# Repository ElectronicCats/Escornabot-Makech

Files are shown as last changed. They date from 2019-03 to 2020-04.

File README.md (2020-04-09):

<a href="https://electroniccats.com/store/escornabot-makech/">
  
</a>

View this project on [CADLAB.io](https://cadlab.io/project/1721). 

# Escornabot Makech
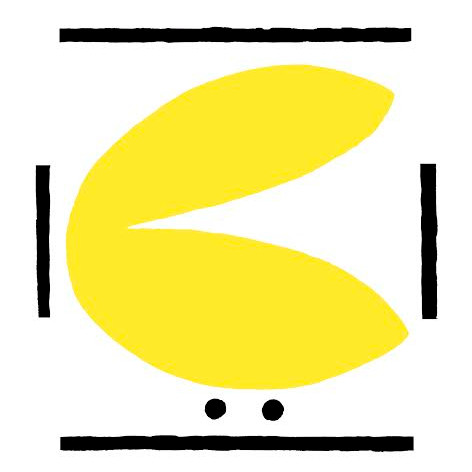
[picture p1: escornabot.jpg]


OSHW

**[OSHW] MX000009 | Certified open source hardware |** [oshwa.org/cert.](https://www.oshwa.org/cert)

Escornabot es un proyecto de código/hardware abierto cuyo objetivo es acercar la robótica y la programación a los niños y niñas.

El Escornabot básico puede programarse con los botones para ejecutar secuencias de movimientos. A partir de aquí, la imaginación es el único límite en las posibilidades.

## Makech
Diseño de robot basado en el Escornabot Ogaki, creado con el microcontrolador SAMD21 Cortex M0 de 32 bits completamente hecho en KiCAD, especialmente creado para enseñar programación con Arduino, MakeCode y CircuitPython.

Al tener todos los circuitos integrados, elimina la necesidad de cablear, minimizando los errores de electrónica, lo que conlleva un incremento en el tiempo dedicado a programación y al conocimiento de nuevos lenguajes de programación.

Con amor para todo el mundo desde Aguascalientes - México.

- Consigue tu kit, visita: [https://electroniccats.com](https://electroniccats.com)

## Ogaki

Diseño de robot basado en el Escornabot, completamente hecho en KiCAD. 

Con amor para todo el mundo desde Malmo - Suecia.

# Créditos

- Escorna CPU 2.20 by [Xdesig](https://github.com/xdesig)

- Los creadores originales de [Escornabot](www.escornabot.com), su comunidad de usuarios y desarrolladores 

# Autor

**Makech - Andrés Sabas and Joe at Electronic Cats**

_Electronic Cats es una empresa de hardware libre hecho en México_

**Ogaki - J. Garcia at abierto.cc**

_Abierto es una inciativa de D. Cuartielles gracias a la generosa aportación de la Fundación PUIG por intermediación de la Fundación Ashoka de cara a contribuir a la creación de material educativo de libre acceso y circulación_

**Escorna CPU 2.20 - XDESIG**

_Nature's walking, Percorrendo a Natureza. Deseñando Electrónica_

# License

Attribution-ShareAlike 4.0 International (CC BY-SA 4.0)
 
Makech - Designed by Electronic Cats.

Hardware released under an CERN Open Hardware Licence v1.2. See the LICENSE_HARDWARE file for more information.

Electronic Cats is a registered trademark, please do not use if you sell these PCBs.

3 Mar 2019

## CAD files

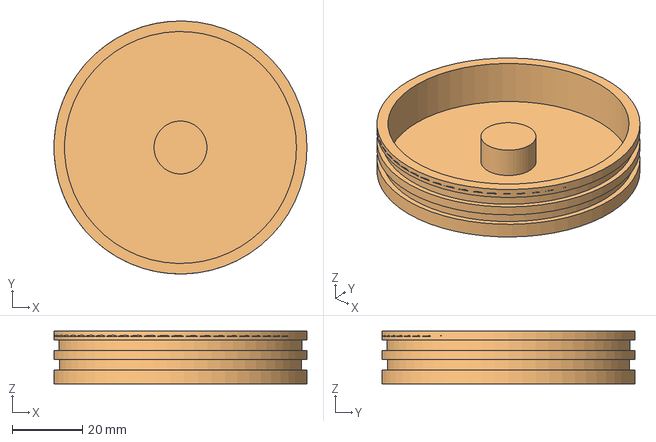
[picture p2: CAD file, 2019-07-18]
Makech/3d/FreeCAD/llantas.FCStd
72.0 x 72.0 x 15.0 mm

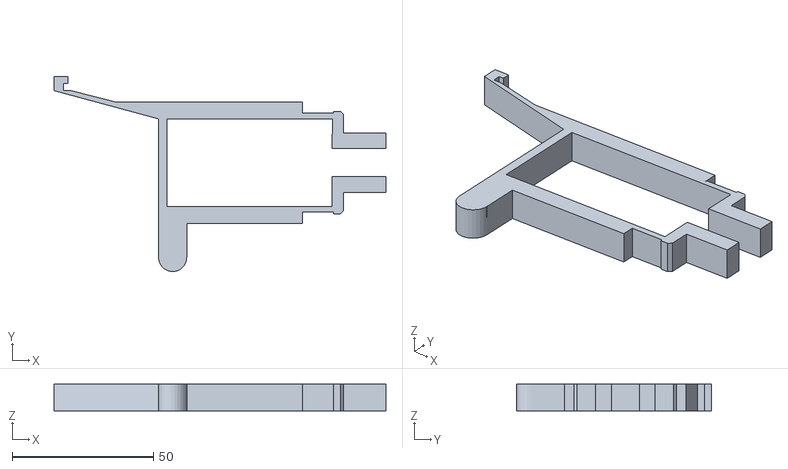
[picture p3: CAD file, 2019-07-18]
Makech/3d/modelado/sop_bat.stl
117.5 x 69.0 x 9.50

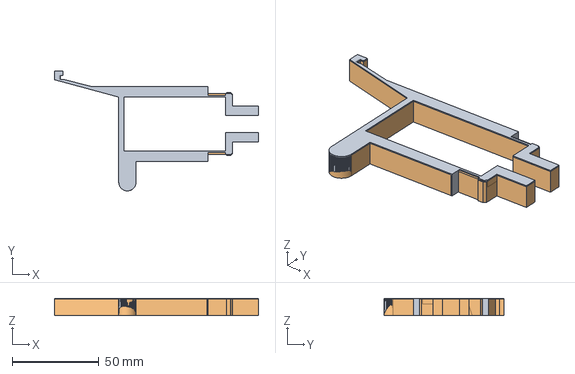
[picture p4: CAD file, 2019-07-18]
Makech/3d/FreeCAD/sop_baterias.FCStd
117.5 x 69.1 x 10.0 mm

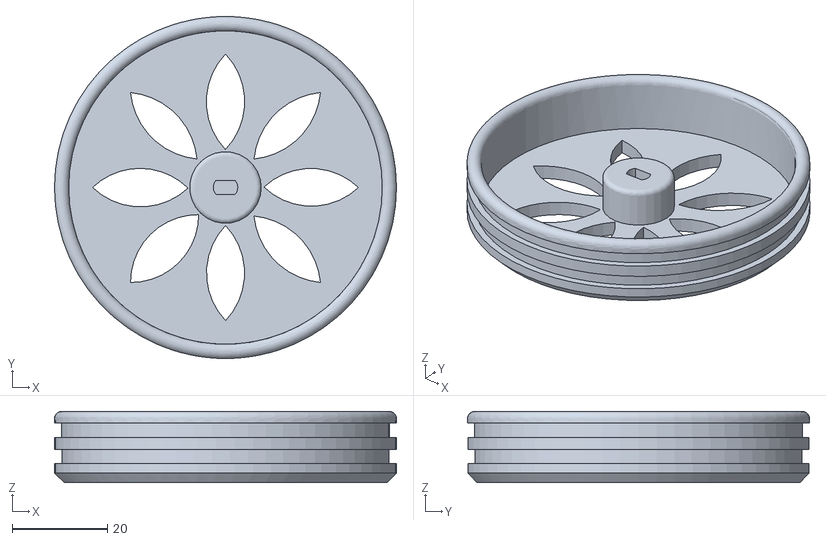
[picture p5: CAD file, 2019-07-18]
Makech/3d/modelado/llanta.stl
72.0 x 72.0 x 15.0

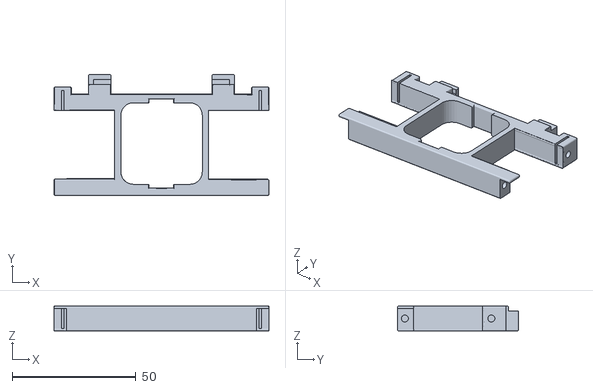
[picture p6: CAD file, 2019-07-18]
Makech/3d/modelado/sop_mot.stl
87.0 x 49.0 x 10.0

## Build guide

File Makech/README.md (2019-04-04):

# Escornabot Makech

Diseño de robot basado en el Escornabot Ogaki, creado con el microcontrolador SAMD21 Cortex M0 de 32 bits completamente hecho en KiCAD, especialmente creado para enseñar programación con Arduino, MakeCode y CircuitPython.

Al tener todos los circuitos integrados, elimina la necesidad de cablear, minimizando los errores de electrónica, lo que conlleva un incremento en el tiempo dedicado a programación y al conocimiento de nuevos lenguajes de programación.
Con amor para todo el mundo desde Aguascalientes - México.

# Consigue tu kit

Si quieres conseguir el kit para montarlo, visita: [https://electroniccats.com](https://electroniccats.com)

# Instrucciones de montaje

Puedes ver las instrucciones de montaje paso a paso en:

# Créditos

Los creadores originales de Escornabot y su comunidad de usuarios y desarrolladores

# Autor

Makech - Andrés Sabas at Electronic Cats

# Electronic Cats

Electronic Cats es una hardware libre hecho en México

Makech - Designed by Electronic Cats.

Hardware released under an CERN Open Hardware Licence v1.2. See the LICENSE_HARDWARE file for more information.

Electronic Cats is a registered trademark, please do not use if you sell these PCBs.

3 Mar 2019

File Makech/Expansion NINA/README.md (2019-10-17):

# Upgrade All-in-One ESP32 Firmware

## Uploading Serial Passthrough Code

Lo primero que se debe realizar es instalar la biblioteca "WiFiNINA" en el arduino library manager y cargar al Escornabot el ejemplo **"Serial Passthrough"**, una vez terminada la carga del firmware continue en el siguiente paso

## Subiendo nina-fw con esptool

¡Esta sección asume que usted sabe cómo usar 'esptool' para cargar firmware a su ESP! Si no está seguro, consulte https://github.com/espressif/esptool y busque tutoriales.
Haga clic en el siguiente enlace para descargar el último archivo .bin de nina-fw. Descomprimir que y guardar el archivo .bin a su escritorio .

Si está utilizando macOS o Linux , ejecute el siguiente comando, reemplazándolo /dev/ttys6con el puerto serie de su placa y  NINA_W102-1.3.0con el archivo binario que está actualizando al ESP32.

esptool.py --port /dev/ttyS6 --before no_reset --baud 115200 write_flash 0 NINA_W102-1.3.0.bin

Si está utilizando Windows , ejecute el siguiente comando, reemplazándolo COM7con el puerto serie de su placa y  NINA_W102-1.3.0con el archivo binario que está actualizando al ESP32

esptool.py --port COM7 --before no_reset --baud 115200 write_flash 0 NINA_W102-1.3.0.bin

El comando debería detectar el ESP32 y tardará uno o dos minutos en cargar el firmware. El NeoPixel en su placa parpadeará y parpadeará a medida que se carga el firmware. 

Si ESPTool no detecta el ESP32 , asegúrese de haber subido el archivo .UF2 correcto al gestor de arranque.



Una vez que el firmware está completamente cargado, el ESP32 se reiniciará y el NeoPixel se iluminará en azul. 

## Verificación de la versión de firmware actualizada

Para verificar que todo funcione correctamente, cargaremos un boceto Arduino o un código CircuitPython. 

Si anteriormente estaba usando su ESP32 con Arduino, debe cargar un boceto de Arduino para verificar que todo funcione correctamente y que la versión del nina-fw se correlaciona con la versión que lee el boceto.

Abra Archivo-> Ejemplos-> WiFiNINA-> ScanNetworks y cargue el boceto. Luego, abra el Monitor de serie. Debería ver la versión del firmware impresa en el monitor serie.



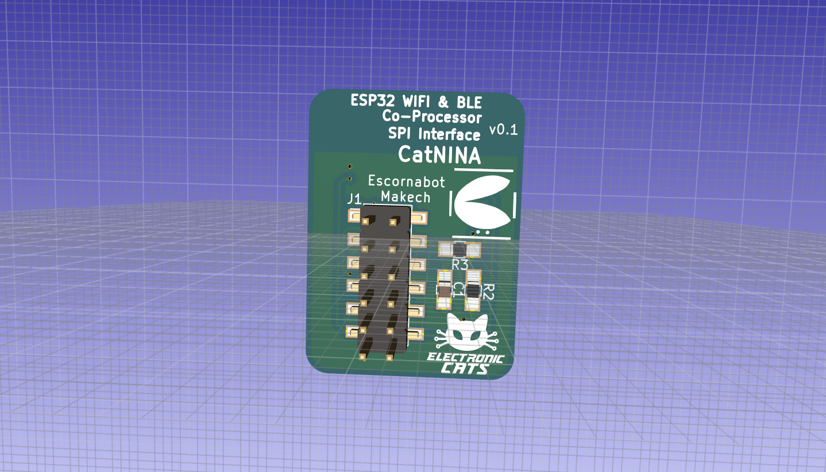
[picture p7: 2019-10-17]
Makech/Expansion NINA/CatNINA_back.png

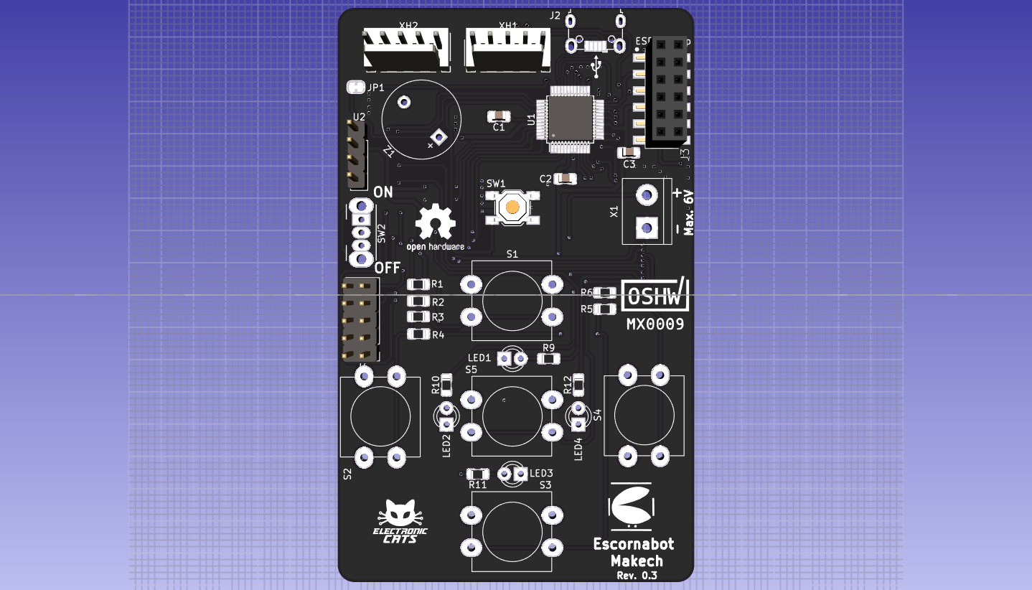
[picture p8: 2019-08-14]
Makech/hardware/KiCad files/Makech_front.png

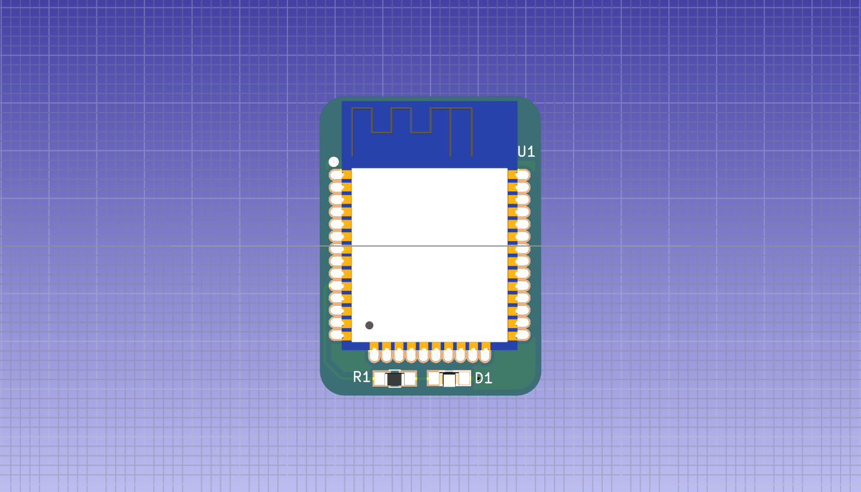
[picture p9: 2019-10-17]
Makech/Expansion NINA/CatNINA.png

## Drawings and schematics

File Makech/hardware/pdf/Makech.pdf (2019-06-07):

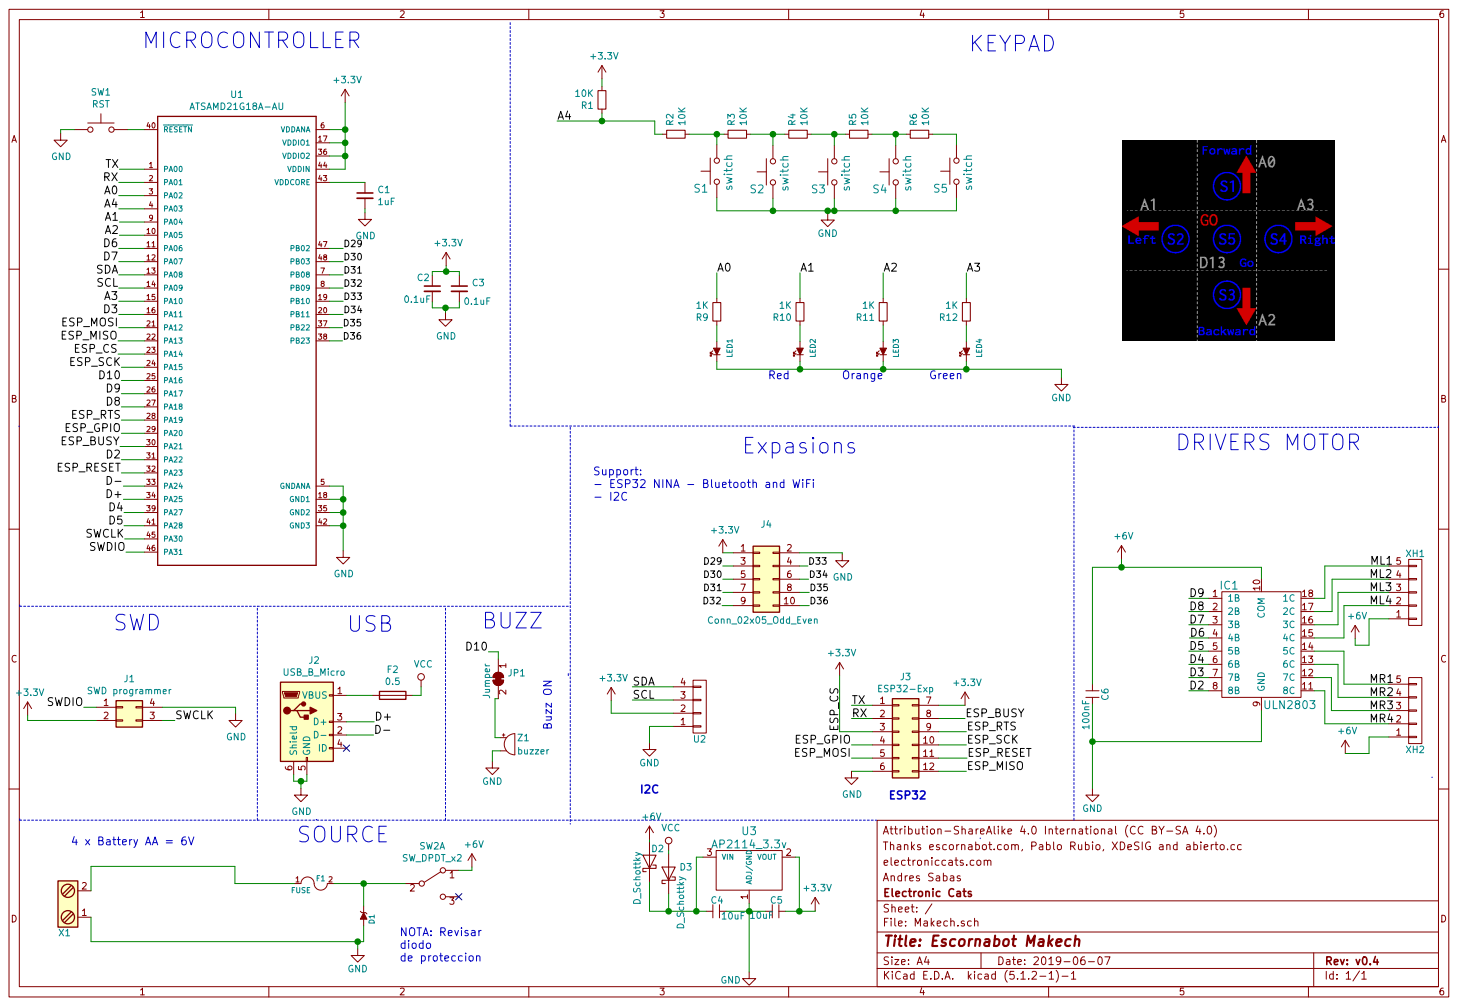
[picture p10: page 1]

- ESP32 NINA - Bluetooth and WiFi

4 | 10
5 | 11

Attribution-ShareAlike 4.0 International (CC BY-SA 4.0)
Thanks escornabot.com, Pablo Rubio, XDeSIG and abierto.cc
File: Makech.sch Sheet: / Electronic Cats Andres Sabas electroniccats.com

Id: 1/1 Title: Escornabot Makech

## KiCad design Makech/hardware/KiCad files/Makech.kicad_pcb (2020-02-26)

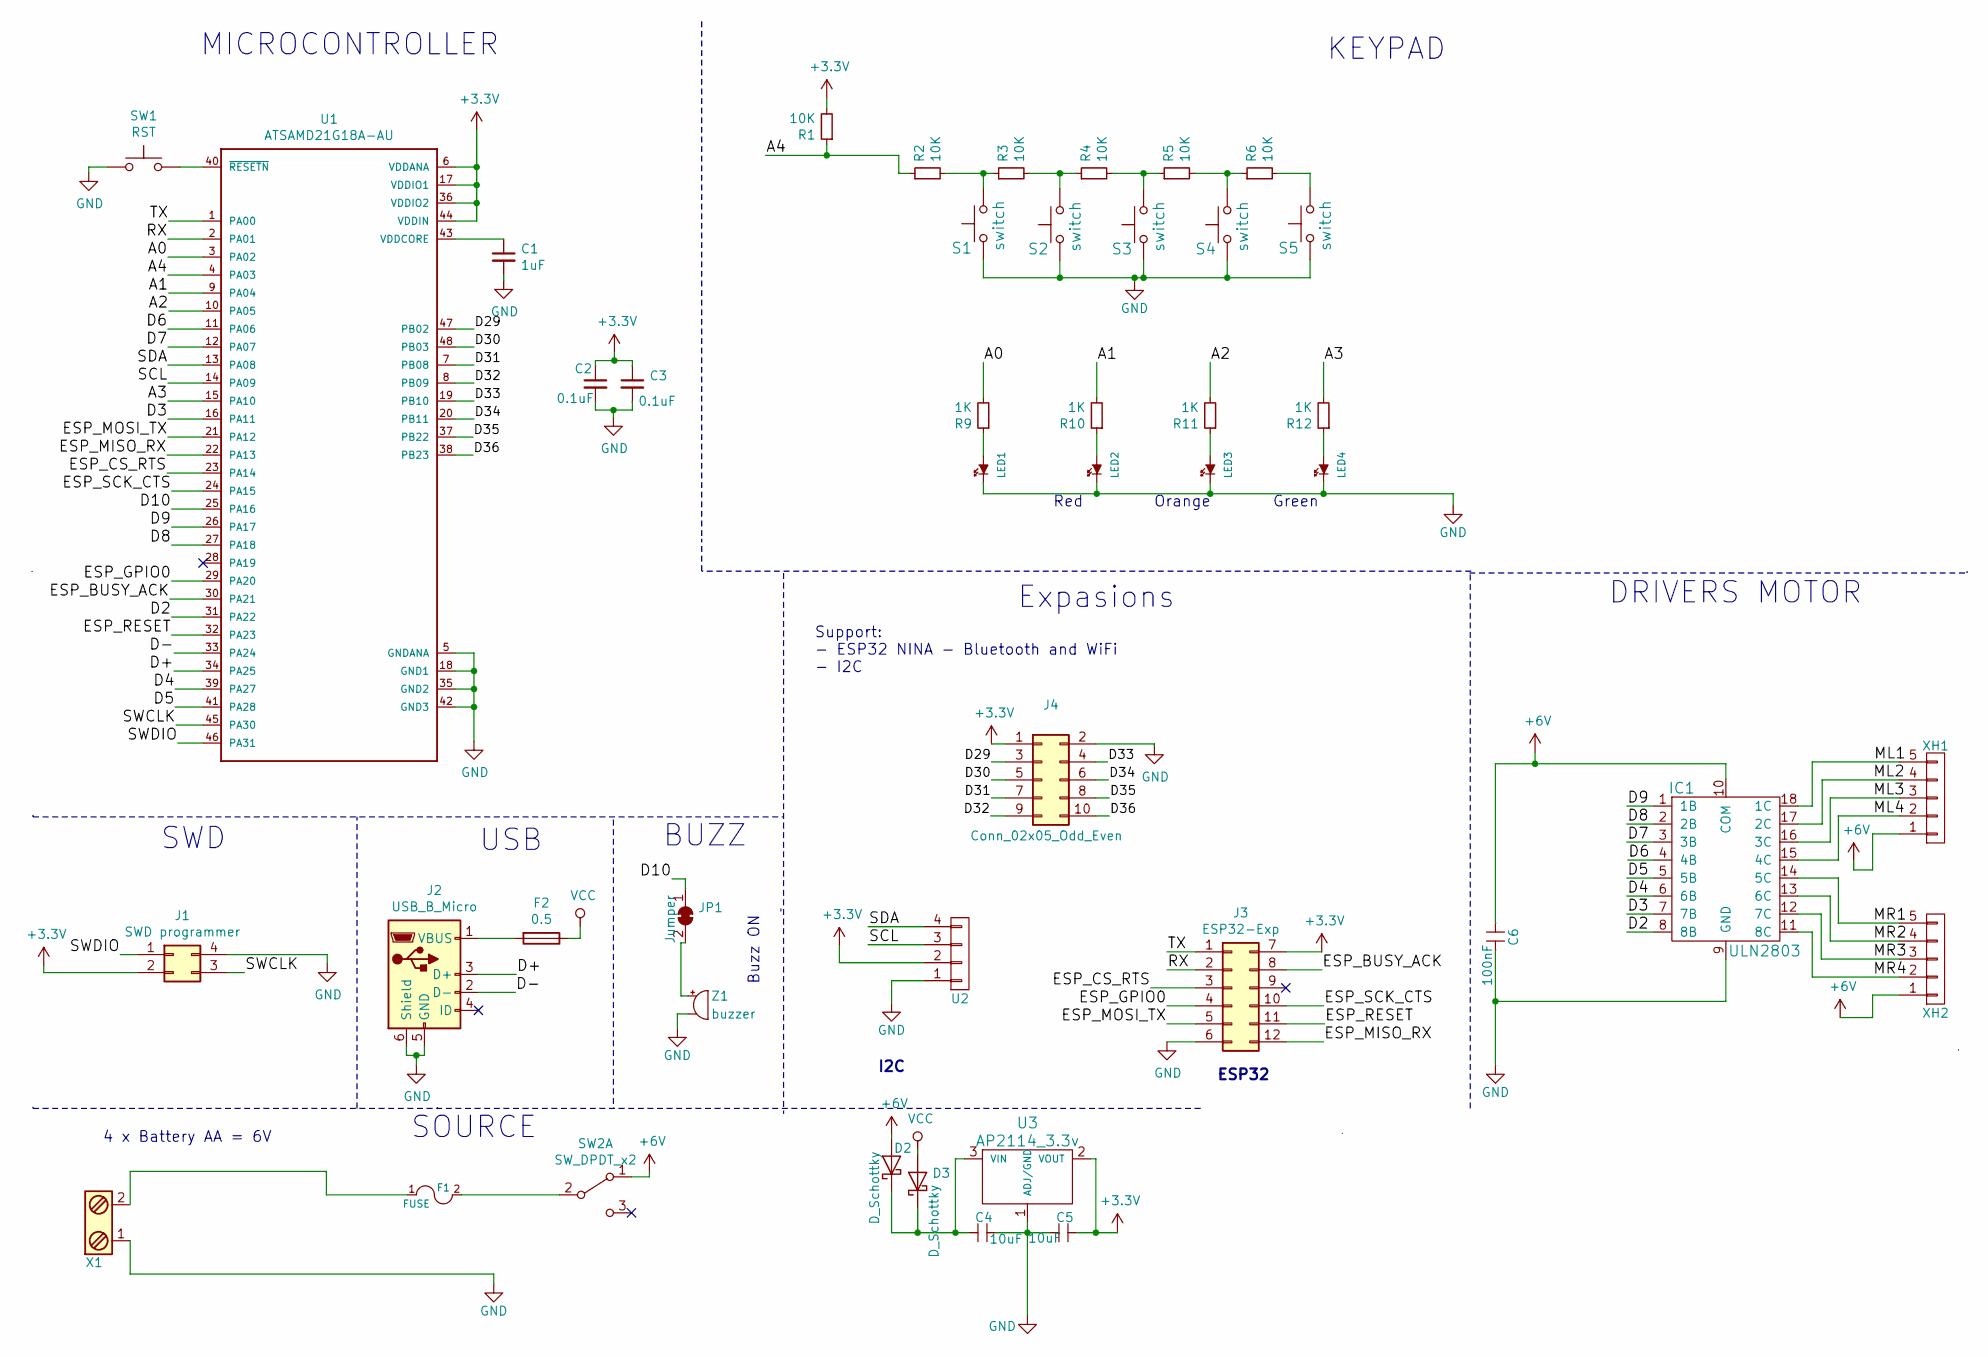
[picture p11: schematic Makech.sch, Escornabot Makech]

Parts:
C1: 1uF; C_0805_2012Metric_Pad1.15x1.40mm_HandSolder
C2, C3: 0.1uF; C_0805_2012Metric_Pad1.15x1.40mm_HandSolder
C4: 10uF; C_0805_2012Metric_Pad1.15x1.40mm_HandSolder
C5: 10uF; C_0805_2012Metric
C6: 100nF; C_0805_2012Metric_Pad1.15x1.40mm_HandSolder
D2, D3: D_Schottky; D_SOD-123
F1: FUSE; R_1812_HandSoldering
F2: 0.5; R_1812_HandSoldering
IC1: ULN2803; SOIC-18W_7.5x11.6mm_P1.27mm
J1: SWD programmer; 621X04245821
J2: USB_B_Micro; U254051N4BH806
J3: ESP32-Exp; 610X1221121
J4: Conn_02x05_Odd_Even; PinHeader_2x05_P2.54mm_Vertical
JP1: Jumper; SolderJumper-2_P1.3mm_Bridged_RoundedPad1.0x1.5mm
LED1, LED2, LED3, LED4: L; LED_D3.0mm
R1, R2, R3, R4, R5, R6: 10K; R_0805_2012Metric_Pad1.15x1.40mm_HandSolder
R9, R10, R11, R12: 1K; R_0805_2012Metric_Pad1.15x1.40mm_HandSolder
S1, S2, S3, S4, S5: switch; SW_PUSH-12mm_Wuerth-430476085716
SW1: RST; SW_SPST_TL3342
SW2: SW_DPDT_x2; SW_CuK_OS102011MA1QN1_SPDT_Angled
U1: ATSAMD21G18A-AU; TQFP-48_7x7mm_P0.5mm
U2: CONN_01X04; PinHeader_1x04_P2.54mm_Vertical
U3: AP2114_3.3v; SOT-223
X1: Screw_Terminal_1x02; TerminalBlock_bornier-2_P5.08mm
XH1, XH2: CONN_01X05; Molex_KK-254_AE-6410-05A_1x05_P2.54mm_Vertical
Z1: buzzer; MagneticBuzzer_ProSignal_ABI-009-RC

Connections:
+3V3: C2.1, C3.1, C5.1, J1.2, J3.7, J4.1, R1.2, U1.6 (VDDANA), U1.17 (VDDIO1), U1.36 (VDDIO2), U1.44 (VDDIN), U2.2, U3.2 (VOUT)
+6V: C6.2, D2.2 (A), IC1.10 (COM), SW2.1 (A), XH1.1, XH2.1
/A0: R9.2, U1.3 (PA02)
/A1: R10.2, U1.9 (PA04)
/A2: R11.2, U1.10 (PA05)
/A3: R12.2, U1.15 (PA10)
/A4: R1.1, R2.1, U1.4 (PA03)
/D2: IC1.8 (8B), U1.31 (PA22)
/D3: IC1.7 (7B), U1.16 (PA11)
/D4: IC1.6 (6B), U1.39 (PA27)
/D5: IC1.5 (5B), U1.41 (PA28)
/D6: IC1.4 (4B), U1.11 (PA06)
/D7: IC1.3 (3B), U1.12 (PA07)
/D8: IC1.2 (2B), U1.27 (PA18)
/D9: IC1.1 (1B), U1.26 (PA17)
/D10: JP1.1 (A), U1.25 (PA16)
/D29: J4.3, U1.47 (PB02)
/D30: J4.5, U1.48 (PB03)
/D31: J4.7, U1.7 (PB08)
/D32: J4.9, U1.8 (PB09)
/D33: J4.4, U1.19 (PB10)
/D34: J4.6, U1.20 (PB11)
/D35: J4.8, U1.37 (PB22)
/D36: J4.10, U1.38 (PB23)
/D+: J2.3 (D+), U1.34 (PA25)
/D-: J2.2 (D-), U1.33 (PA24)
/ESP_BUSY_ACK: J3.8, U1.30 (PA21)
/ESP_CS_RTS: J3.3, U1.23 (PA14)
/ESP_GPIO0: J3.4, U1.29 (PA20)
/ESP_MISO_RX: J3.12, U1.22 (PA13)
/ESP_MOSI_TX: J3.5, U1.21 (PA12)
/ESP_RESET: J3.11, U1.32 (PA23)
/ESP_SCK_CTS: J3.10, U1.24 (PA15)
/ML1: IC1.18 (1C), XH1.5
/ML2: IC1.17 (2C), XH1.4
/ML3: IC1.16 (3C), XH1.3
/ML4: IC1.15 (4C), XH1.2
/MR1: IC1.14 (5C), XH2.5
/MR2: IC1.13 (6C), XH2.4
/MR3: IC1.12 (7C), XH2.3
/MR4: IC1.11 (8C), XH2.2
/RX: J3.2, U1.2 (PA01)
/SCL: U1.14 (PA09), U2.3
/SDA: U1.13 (PA08), U2.4
/SWCLK: J1.3, U1.45 (PA30)
/SWDIO: J1.1, U1.46 (PA31)
/TX: J3.1, U1.1 (PA00)
GND: C1.2, C2.2, C3.2, C4.1, C5.2, C6.1, IC1.9 (GND), J1.4, J2.5 (GND), J2.6 (Shield), J3.6, J4.2, LED1.1 (K), LED2.1 (K), LED3.1 (K), LED4.1 (K), S1.1, S2.1, S3.1, S4.1, S5.1, SW1.1, U1.5 (GNDANA), U1.18 (GND1), U1.35 (GND2), U1.42 (GND3), U2.1, U3.1 (ADJ/GND), X1.1, Z1.2
unnamed: C1.1, U1.43 (VDDCORE)
unnamed: C4.2, D2.1 (K), D3.1 (K), U3.3 (VIN)
unnamed: F1.2, SW2.2 (B)
unnamed: F1.1, X1.2
unnamed: F2.2, J2.1 (VBUS)
unnamed: JP1.2 (B), Z1.1
unnamed: LED1.2 (A), R9.1
unnamed: LED2.2 (A), R10.1
unnamed: LED3.2 (A), R11.1
unnamed: LED4.2 (A), R12.1
unnamed: R2.2, R3.1, S1.2
unnamed: R3.2, R4.1, S2.2
unnamed: R4.2, R5.1, S3.2
unnamed: R5.2, R6.1, S4.2
unnamed: R6.2, S5.2
unnamed: SW1.2, U1.40 (~RESETN~)
VCC: D3.2 (A), F2.1

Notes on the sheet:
KEYPAD
BUZZ
Buzz ON
I2C
Expasions
Red
Orange
Green
4 x Battery AA = 6V
MICROCONTROLLER
Support: - ESP32 NINA - Bluetooth and WiFi - I2C
DRIVERS MOTOR
USB
SWD
ESP32
SOURCE

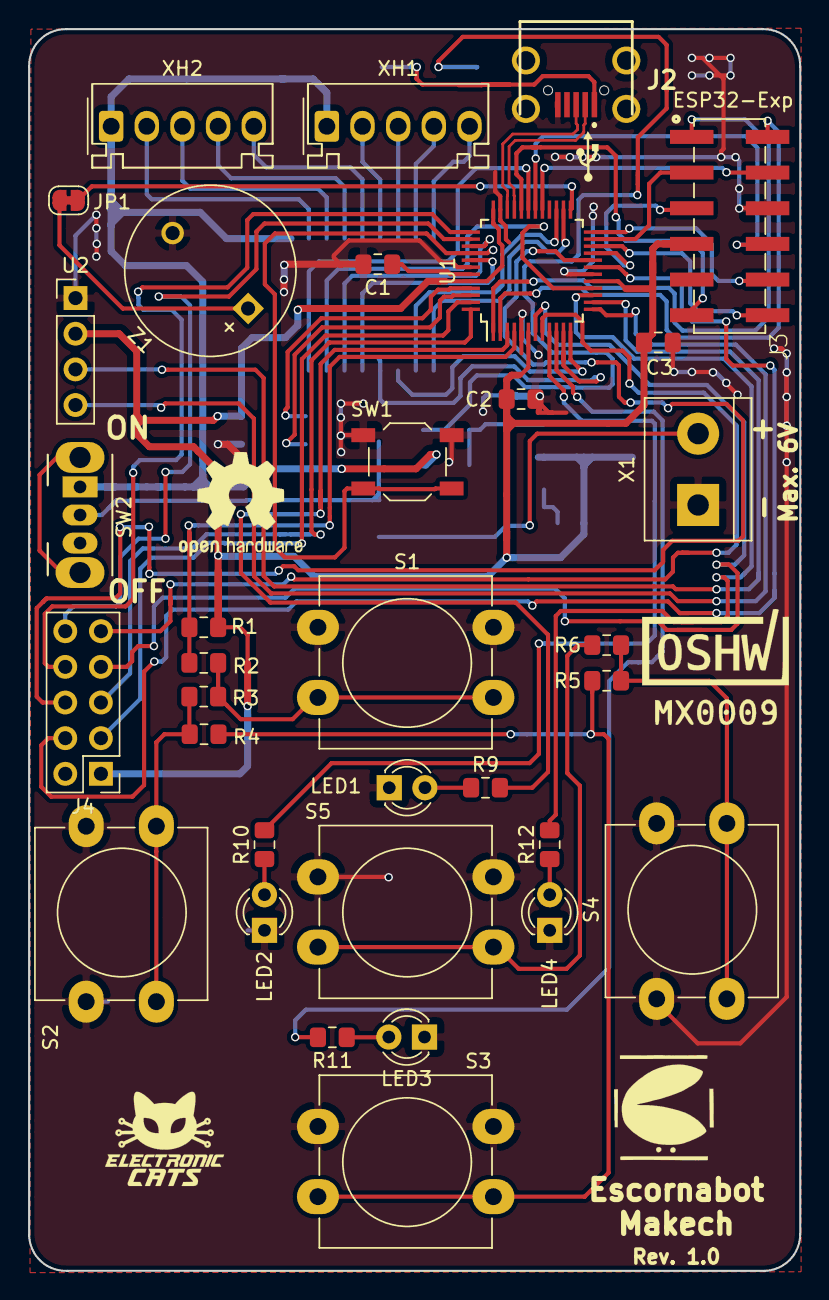
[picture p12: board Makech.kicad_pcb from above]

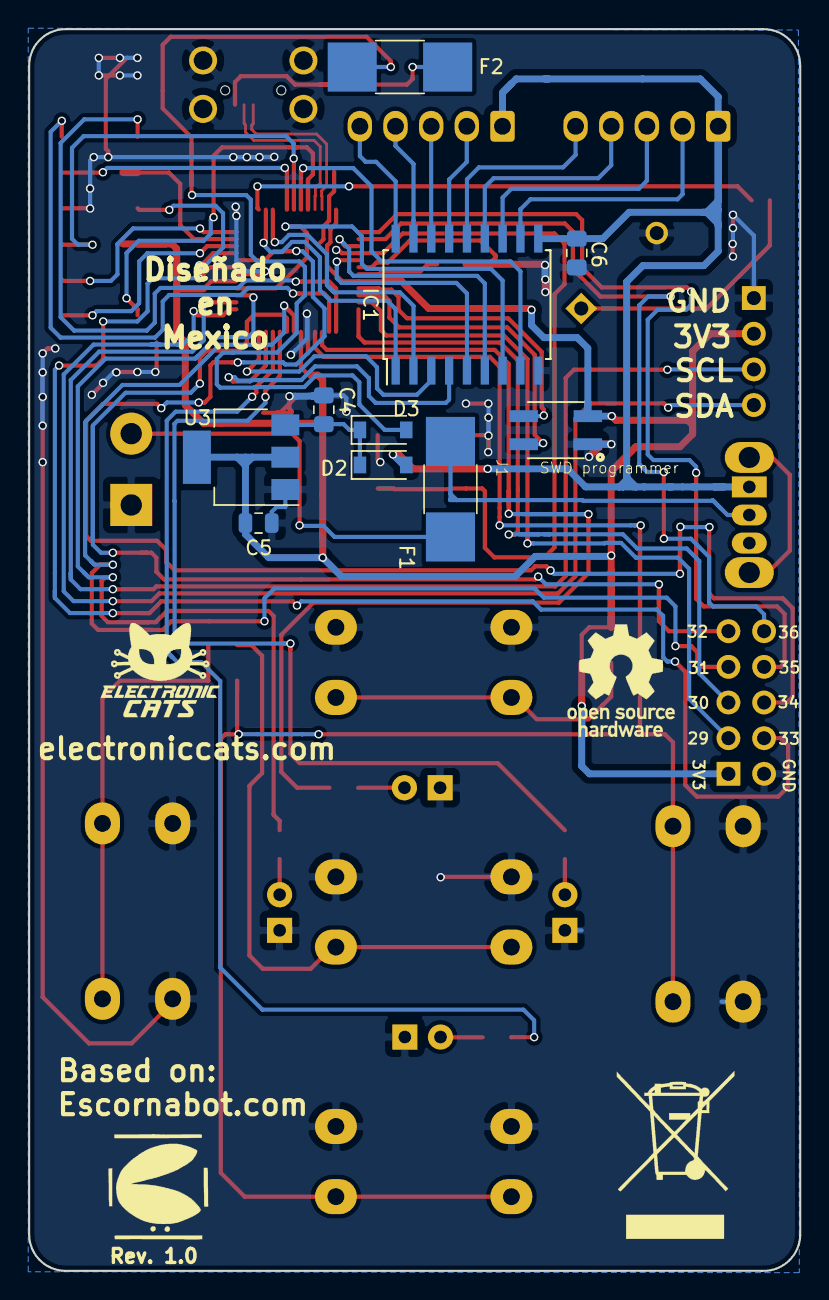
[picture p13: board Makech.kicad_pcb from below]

Board: 2 copper layers, 54.9 x 88.5 mm, 45 parts (10 on the bottom side), 65 nets.

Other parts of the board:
svg2mod: G***; usb_graphic

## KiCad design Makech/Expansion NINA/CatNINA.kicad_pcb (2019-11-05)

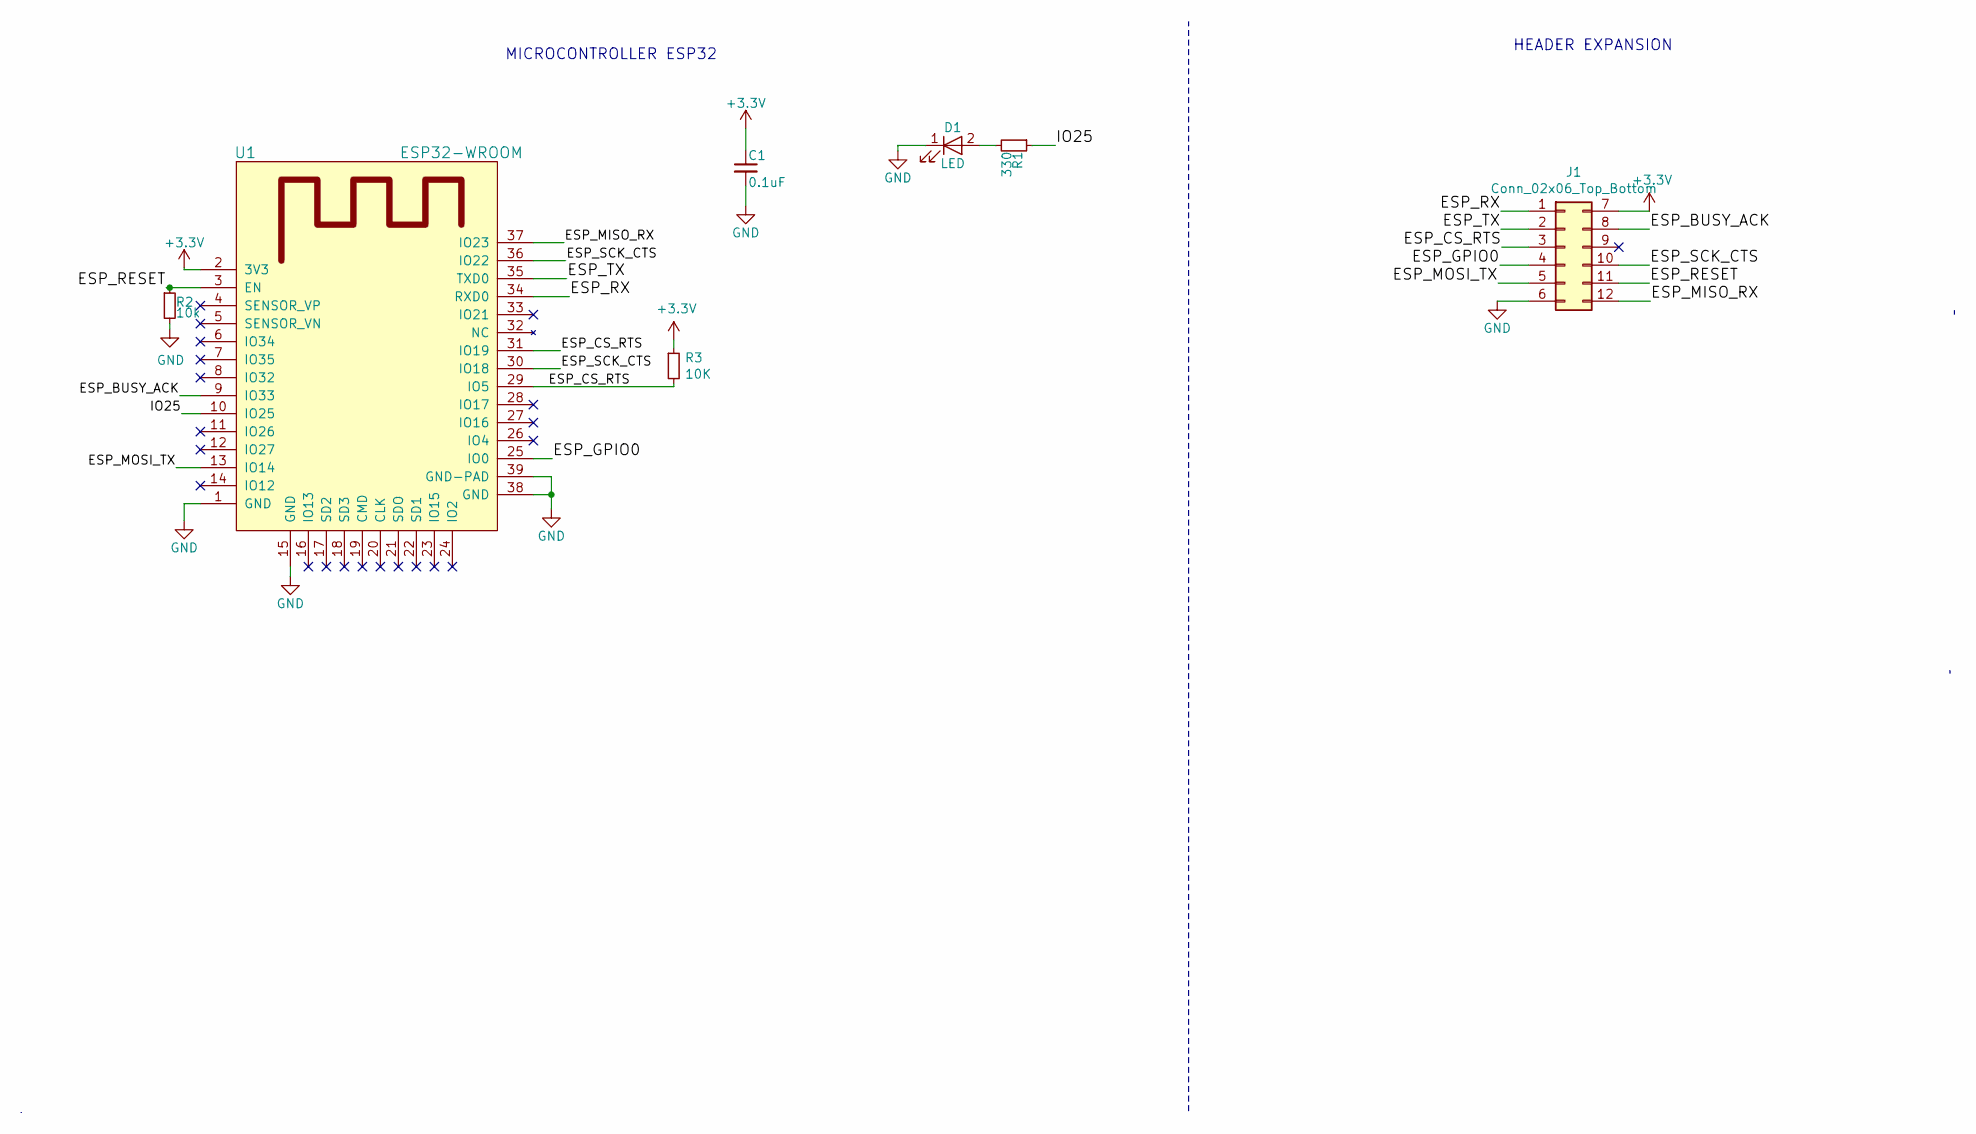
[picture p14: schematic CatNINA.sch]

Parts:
C1: 0.1uF; C_0805_HandSoldering
D1: LED; LED_0805_HandSoldering
J1: Conn_02x06_Top_Bottom; 61301221121
R1: 330; R_0805_HandSoldering
R2: 10k; R_0805_HandSoldering
R3: 10K; R_0805_HandSoldering
U1: ESP32-WROOM

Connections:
+3V3: C1.1, J1.7, R3.1, U1.2 (3V3)
/ESP_BUSY_ACK: J1.8, U1.9 (IO33)
/ESP_CS_RTS: J1.3, R3.2, U1.29 (IO5), U1.31 (IO19)
/ESP_GPIO0: J1.4, U1.25 (IO0)
/ESP_MISO_RX: J1.12, U1.37 (IO23)
/ESP_MOSI_TX: J1.5, U1.13 (IO14)
/ESP_RESET: J1.11, R2.1, U1.3 (EN)
/ESP_RX: J1.1, U1.34 (RXD0)
/ESP_SCK_CTS: J1.10, U1.30 (IO18), U1.36 (IO22)
/ESP_TX: J1.2, U1.35 (TXD0)
/IO25: R1.1, U1.10 (IO25)
GND: C1.2, D1.1 (K), J1.6, R2.2, U1.1 (GND), U1.15 (GND), U1.38 (GND), U1.39 (GND-PAD)
unnamed: D1.2 (A), R1.2

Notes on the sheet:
MICROCONTROLLER ESP32
HEADER EXPANSION

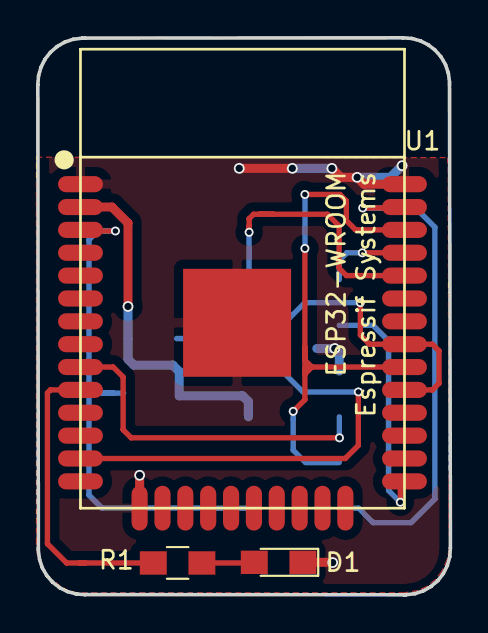
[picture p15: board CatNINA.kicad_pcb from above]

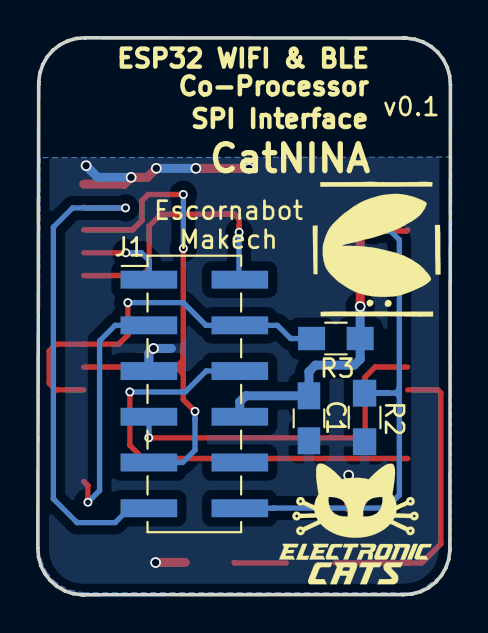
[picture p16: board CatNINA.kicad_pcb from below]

Board: 2 copper layers, 22.9 x 30.9 mm, 7 parts (4 on the bottom side), 13 nets.

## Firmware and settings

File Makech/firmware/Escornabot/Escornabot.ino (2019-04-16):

// Escornabot.ino
/*

Copyright (C) 2014-2019 Escornabot - http://escornabot.com

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
See LICENSE.txt for details

*/

#include "Bot.h"

//////////////////////////////////////////////////////////////////////

// instance
Bot ESCORNABOT;

//////////////////////////////////////////////////////////////////////

void setup()
{
    ESCORNABOT.init();
}

//////////////////////////////////////////////////////////////////////

void loop()
{
    ESCORNABOT.loop();
}

//////////////////////////////////////////////////////////////////////


// EOF

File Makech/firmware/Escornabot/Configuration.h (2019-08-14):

// Configuration.h
/*

Copyright (C) 2014-2019 Escornabot - http://escornabot.com

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
See LICENSE.txt for details

*/

#ifndef _CONFIGURATION_H
#define _CONFIGURATION_H


//////////////////////////////////////////////////////////////////////
///// general configuration
//////////////////////////////////////////////////////////////////////

// engine to use
#define ENGINE_TYPE_STEPPERS

// button set to use (analog input, digital input)
#define BUTTONS_ANALOG
//#define BUTTONS_DIGITAL

// milliseconds after a button is considered as pressed
#define BUTTON_MIN_PRESSED 30

// milliseconds after a button is considered as long pressed
#define BUTTON_LONG_PRESSED 1000

// put to false to add movements to the program after its execution
#define PROGRAM_RESET_ALWAYS true

// store configuration and program within internal EEPROM
/* 
 * WARNING!!: FALSE for SAMD21, EEPROM not compatible 
 */
#define USE_PERSISTENT_MEMORY false

// memory capacity for program movements
#define MOVE_LIMIT 100

// milliseconds for the "pause" movement
#define PAUSE_MOVE_MILLIS 1000

// milliseconds delay before starting to move
#define DELAY_BEFORE_GO 500

// milliseconds to pause after every movement
#define AFTER_MOVEMENT_PAUSE 0

// point of view set when Vacalourabot is started
#define POV_INITIAL    POV_ESCORNABOT

// bluetooth serial
#define USE_BLUETOOTH false
#define BLUETOOTH_BAUDS 9600

// buzzer
#define USE_BUZZER true
#define BUZZER_PIN 10
#define PROGRAM_FINISHED_RTTL RTTL_FIDO
#define TONE_FREQ_UP 2637
#define TONE_FREQ_RIGHT 4434
#define TONE_FREQ_DOWN 3520
#define TONE_FREQ_LEFT 2217

// simple led
#define USE_SIMPLE_LED false
#define SIMPLE_LED_PIN LED_BUILTIN

// keypad leds
#define USE_KEYPAD_LEDS true
#define KEYPAD_LED_PIN_UP A1
#define KEYPAD_LED_PIN_RIGHT A0
#define KEYPAD_LED_PIN_DOWN A3
#define KEYPAD_LED_PIN_LEFT A2
#define KEYPAD_LED_PIN_GO -1


//////////////////////////////////////////////////////////////////////
///// Steppers engine setup
//////////////////////////////////////////////////////////////////////

#ifdef ENGINE_TYPE_STEPPERS

// stepper pin setup (digital outputs)
#define STEPPERS_MOTOR_RIGHT_IN1 6
#define STEPPERS_MOTOR_RIGHT_IN2 7
#define STEPPERS_MOTOR_RIGHT_IN3 8
#define STEPPERS_MOTOR_RIGHT_IN4 9
#define STEPPERS_MOTOR_LEFT_IN1 5
#define STEPPERS_MOTOR_LEFT_IN2 4
#define STEPPERS_MOTOR_LEFT_IN3 3
#define STEPPERS_MOTOR_LEFT_IN4 2

// step calibration
#define STEPPERS_STEPS_PER_SECOND 1000
#define STEPPERS_LINE_STEPS 1500
#define STEPPERS_TURN_STEPS 1900

#endif



//////////////////////////////////////////////////////////////////////
///// Button set digital
//////////////////////////////////////////////////////////////////////

#ifdef BUTTONS_DIGITAL

// keypad pin setup (digital or analog inputs) (use 255 if key doesn't exist)
#define BS_DIGITAL_UP A0
#define BS_DIGITAL_RIGHT A1
#define BS_DIGITAL_DOWN A2
#define BS_DIGITAL_LEFT A3
#define BS_DIGITAL_GO A4
#define BS_DIGITAL_RESET 255

#endif // BUTTONS_DIGITAL



//////////////////////////////////////////////////////////////////////
///// Button set analog
//////////////////////////////////////////////////////////////////////

#ifdef BUTTONS_ANALOG

#define BS_ANALOG_WIRES 2
//#define BS_ANALOG_WIRES 3

// keypad pin setup (analog input)
#define BS_ANALOG_PIN A4

// input values for each key pressed (0 if key doesn't exist)
#define BS_ANALOG_VALUE_UP 680
#define BS_ANALOG_VALUE_RIGHT 509
#define BS_ANALOG_VALUE_DOWN 816
#define BS_ANALOG_VALUE_LEFT 765
#define BS_ANALOG_VALUE_GO 873
#define BS_ANALOG_VALUE_RESET 0

#endif // BUTTONS_ANALOG



//////////////////////////////////////////////////////////////////////
///// Button set Bluetooth
//////////////////////////////////////////////////////////////////////

#ifdef USE_BLUETOOTH

// Arduino serial port (default is Serial, use Serial1 with Arduino Micro and Makech)
//#define BLUETOOTH_SERIAL    Serial
#define BLUETOOTH_SERIAL    Serial1
//#define BLUETOOTH_SERIAL    Serial2
//#define BLUETOOTH_SERIAL    Serial3

#endif // USE_BLUETOOTH




//////////////////////////////////////////////////////////////////////
//////////////////////////////////////////////////////////////////////


#endif // _CONFIGURATION_H

// EOF

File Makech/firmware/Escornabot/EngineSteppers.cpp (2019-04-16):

// EngineSteppers.cpp
/*

Copyright (C) 2014-2019 Escornabot - http://escornabot.com

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
See LICENSE.txt for details

*/

#include "EngineSteppers.h"
#include "EventManager.h"
#include <Arduino.h>

//////////////////////////////////////////////////////////////////////

const static uint8_t step_pattern[] = {
    B00001, B00011, B00010, B00110, B00100, B01100, B01000, B01001
};

//////////////////////////////////////////////////////////////////////

extern EventManager* EVENTS;

//////////////////////////////////////////////////////////////////////

EngineSteppers::EngineSteppers(const Config* cfg)
{
    _config = cfg;

    _movement_steps_r = 0;
    _movement_steps_l = 0;

    _pattern_index_left = 0;
    _pattern_index_right = 0;
}

//////////////////////////////////////////////////////////////////////

void EngineSteppers::init()
{
    pinMode(_config->motor_left_in1, OUTPUT);
    pinMode(_config->motor_left_in2, OUTPUT);
    pinMode(_config->motor_left_in3, OUTPUT);
    pinMode(_config->motor_left_in4, OUTPUT);
    pinMode(_config->motor_right_in1, OUTPUT);
    pinMode(_config->motor_right_in2, OUTPUT);
    pinMode(_config->motor_right_in3, OUTPUT);
    pinMode(_config->motor_right_in4, OUTPUT);

    // set coils in row
    _movement_steps_r = 8;
    _movement_steps_l = 8;

    EVENTS->add(this);
}

//////////////////////////////////////////////////////////////////////

void EngineSteppers::turn(int16_t degrees)
{
    int32_t steps = -_config->turn_steps;
    steps *= degrees;
    steps /= 90;

    _movement_steps_r = steps;
    _movement_steps_l = steps;
}

//////////////////////////////////////////////////////////////////////

void EngineSteppers::moveStraight(float advance_units)
{
    _movement_steps_r = _config->line_steps * advance_units;
    _movement_steps_l = -_movement_steps_r;
}

//////////////////////////////////////////////////////////////////////

void EngineSteppers::_motorStepRight(uint8_t pattern)
{
    digitalWrite(_config->motor_right_in1, bitRead(pattern, 0));
    digitalWrite(_config->motor_right_in2, bitRead(pattern, 1));
    digitalWrite(_config->motor_right_in3, bitRead(pattern, 2));
    digitalWrite(_config->motor_right_in4, bitRead(pattern, 3));
}

//////////////////////////////////////////////////////////////////////

void EngineSteppers::_motorStepLeft(uint8_t pattern)
{
    digitalWrite(_config->motor_left_in1, bitRead(pattern, 0));
    digitalWrite(_config->motor_left_in2, bitRead(pattern, 1));
    digitalWrite(_config->motor_left_in3, bitRead(pattern, 2));
    digitalWrite(_config->motor_left_in4, bitRead(pattern, 3));
}

//////////////////////////////////////////////////////////////////////

void EngineSteppers::tick(uint32_t micros)
{
    if (!isExecuting()) return;

    if (_movement_steps_l == 0 && _movement_steps_r == 0)
    {
        // already executing a pause movement
        if (_inPauseMove()) return;

        // deactivate Darlingtons
        _motorStepLeft(0);
        _motorStepRight(0);

        EVENTS->indicateMoveExecuted(_getCurrentMove());

        // prepare next movement
        _program_index++;
        _prepareMove();
        return;
    }

    if (_movement_steps_l != 0)
    {
        // left motor step
        int8_t delta = (_movement_steps_l > 0 ? 1 : -1);
        _motorStepLeft(step_pattern[_pattern_index_left]);
        _pattern_index_left += delta + 8;
        _pattern_index_left %= 8;
        _movement_steps_l -= delta;
    }

    if (_movement_steps_r != 0)
    {
        // right motor step
        int8_t delta = (_movement_steps_r > 0 ? 1 : -1);
        _motorStepRight(step_pattern[_pattern_index_right]);
        _pattern_index_right += delta + 8;
        _pattern_index_right %= 8;
        _movement_steps_r -= delta;
    }

    if (_is_cancelling)
    {
        _movement_steps_r = 0;
        _movement_steps_l = 0;
    }
    else
    {
        delayMicroseconds(1000000 / _config->steps_per_second);
    }
}

//////////////////////////////////////////////////////////////////////

// EOF

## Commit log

2019-02-10 kicad init
    [Makech.kicad_pcb, Makech.sch]
2019-02-10 model 3d thanks Ogaki
    [ballcaster.fcstd, ballcaster.stl, battery-bracket.fcstd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]
2019-02-10 update README de Makech
2019-02-10 Init firmware compatible SAMD21
    [Configuration.h]
2019-02-10 clean pcb for new desing
    [Makech.kicad_pcb]
2019-02-10 init select footprint
    [Makech.sch]
2019-02-10 add usb description
    [Makech.sch]
2019-02-25 init BOM
    [Makech.kicad_pcb, Makech.sch]
2019-02-27 Header ESP32 Expansion
    [Makech.sch]
2019-02-28 BOM complete
    [Makech.sch]
2019-03-01 Update autors CC
    Thanks escornabot.com, Pablo Rubio, XDeSIG and abierto.cc
    [Makech.sch]
2019-03-02 migrate to SAMD21G18
    [Makech.sch]
2019-03-04 update v0.2
    migrate to SAMD21G
    [Makech.sch]
2019-03-04 assign pins
    [Makech.sch]
2019-03-04 SPI for ESP32
    [Makech.sch]
2019-03-04 Eliminate unnecessary elements
    [Makech.sch]
2019-03-04 Schematic v0.2
2019-03-04 remove furubot without support
    [Configuration.h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]
2019-03-09 Fix error library index
    [Makech.sch]
2019-03-09 remove components x.1
    [Makech.sch]
2019-03-09 cache lib
    [Makech.sch]
2019-03-15 Footprint complet
    [Makech.kicad_pcb, Makech.sch]
2019-03-19 USB correct
    [Makech.sch]
2019-03-23 pre router
    [Makech.kicad_pcb]
2019-03-23 update silk
    [Makech.kicad_pcb]
2019-03-24 change leds 3mm
    [Makech.kicad_pcb, Makech.sch]
2019-03-24 remove jumper extra and capacitors
    [Makech.kicad_pcb, Makech.sch]
2019-03-24 Fix source motors
    [Makech.sch]
2019-03-24 fix source motor pcb
    [Makech.kicad_pcb]
2019-03-24 add symbol jumper
    [Makech.sch]
2019-03-24 update labels
    [Makech.sch]
2019-03-26 fix pcb
    [Makech.kicad_pcb]
2019-03-26 fix2 pcb
    [Makech.kicad_pcb]
2019-03-26 capacitors sources
    [Makech.kicad_pcb]
2019-03-28 PCB COMPLETE
    [Makech.kicad_pcb]
2019-03-29 update Silks
    [Makech.kicad_pcb]
2019-03-29 foot-print change
    [Makech.kicad_pcb, Makech.sch]
2019-04-16 Update firmware version 2019
    [Configuration.h]
2019-04-29 Re-define pins for Arduino and Makecode in Schematic
    [Makech.sch]
2019-04-29 Update Description
    [Configuration.h]
2019-04-29 Schematic PDF
2019-04-29 Change connector ESP32, SWD and logo OSWHA
    [Makech.kicad_pcb, Makech.sch]
2019-04-30 rename path
    [Configuration.h]
2019-05-10 update value for button
    [Configuration.h]
2019-05-11 change terminal block
    [Makech.kicad_pcb, Makech.sch]
2019-05-11 Change routing and compnent placement v0.2
    [Makech.kicad_pcb]
2019-05-11 Fix traces
    [Makech.kicad_pcb]
2019-05-11 Fix clearance and GND traces
    [Makech.kicad_pcb]
2019-05-11 Clearance gnd bottom fix
    [Makech.kicad_pcb]
2019-05-13 Update Silks for v0.2
    [Makech.kicad_pcb]
2019-05-14 Change Fusible and add conector expansion
    [Makech.kicad_pcb, Makech.sch]
2019-05-15 Fix edge cuts mm
    [Makech.kicad_pcb]
2019-05-17 route digital outputs and fusibes
    [Makech.kicad_pcb]
2019-05-28 init CatNINA
    [CatNINA.kicad_pcb, CatNINA.sch]
2019-05-28 Init PCB and netlist
    [CatNINA.kicad_pcb, CatNINA.sch]
2019-05-29 size in margin
    [CatNINA.kicad_pcb]
2019-05-29 update schematic
    [CatNINA.sch]
2019-05-29 Fix Line and Turn steps
    Thanks @ForeverWero
    [Configuration.h]
2019-05-30 routeo NINA
    [CatNINA.kicad_pcb, _saved_CatNINA.sch]
2019-06-03 model 3D CatNiNA
    [CatNINA.kicad_pcb, Makech.kicad_pcb]
2019-06-03 fix text escornabot
    [CatNINA.kicad_pcb]
2019-06-03 move connector
    [CatNINA.kicad_pcb]
2019-06-03 .step nina
    [Makech.kicad_pcb]
2019-06-03 routeo moved connector
    [CatNINA.kicad_pcb]
2019-06-04 change mesure layer
    [CatNINA.kicad_pcb]
2019-06-05 add man # to connector
    [CatNINA.sch]
2019-06-06 Fix error NINA_RESET to GND
    [Makech.sch]
2019-06-06 change TX and RX
    [CatNINA.kicad_pcb]
2019-06-06 move conector
    [CatNINA.kicad_pcb, CatNINA.sch, _saved_CatNINA.sch]
2019-06-07 pin reset move of gnd
    [Makech.kicad_pcb]
2019-06-10 CS fix voltage
    [Makech.sch]
2019-06-11 Remove CS tracks to voltage
    [Makech.kicad_pcb]
2019-06-11 Update connector to 2.54mm and fix traces and ground plane
    [Makech.kicad_pcb, Makech.sch]
2019-06-19 Update traces fix ground missed
    [Makech.kicad_pcb]
2019-07-17 new calibration for new case
    [Configuration.h]
2019-07-18 escornabot plug and play version
    [llanta.stl, llantas.FCStd, sop_bat.stl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]
2019-07-18 Fix path and names
    [ballcaster.fcstd, ballcaster.stl, battery-bracket.fcstd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]
2019-08-14 change values configuration
    [Configuration.h]
2019-08-14 update v3
    [Makech.kicad_pcb]
2019-08-14 update nina v0.1
    [CatNINA.kicad_pcb]
2019-08-14 update BOM
    [Makech.sch]
2019-10-17 Create Upgrade All-in-One ESP32.md
2019-10-17 Rename Upgrade All-in-One ESP32.md to README.md
2019-10-20 Init fix connection for BLE
    [Makech.sch]
2019-10-20 init cat nina support BLE
    [CatNINA.sch, Makech.sch]
2019-10-20 rename mosi and miso
    [Makech.sch]
2019-10-20 remove not connect lines
    [CatNINA.sch, Makech.sch]
2019-10-29 Update vias
    [Makech.kicad_pcb]
2019-10-29 brush traces
    [Makech.kicad_pcb]
2019-10-29 update traces WiFiNINA
    [CatNINA.kicad_pcb]
2019-10-29 Add footprint to local library erase track
    [Makech.kicad_pcb]
2019-11-15 Update USB connector and Version 1.0
    [Makech.kicad_pcb, Makech.sch]
2020-02-26 remove Diode zener innecesary
    [Makech.kicad_pcb, Makech.sch]

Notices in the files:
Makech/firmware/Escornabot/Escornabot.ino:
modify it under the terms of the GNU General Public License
